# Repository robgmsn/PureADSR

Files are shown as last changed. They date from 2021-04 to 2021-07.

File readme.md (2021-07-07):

DESIGN STATUS: Production

ADSR Updated to V2.21 5/5/21

Library updated to include 3D models.
Traces rerouted.
DAC output filter remodelled.
Power replaced so 5V comes from power supply rather than 12V, in line with low noise techniques.
Code rewritten to be linear, as required by all other GMSN! modules.

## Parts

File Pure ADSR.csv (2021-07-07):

Library | Qty | Parts | Description | Value | Package | SORT
GMSN | 3 | R6, R11, R12 | Resistor | 100k | R0805 | 2
GMSN | 2 | R5, R9 | Resistor | 10k | R0805 | 2
GMSN | 1 | R7 | Resistor | 1M | R0805 | 2
GMSN | 2 | R8, R10 | Resistor | 1k | R0805 | 2
GMSN | 1 | R1 | Resistor | 1k6 | R0805 | 2
GMSN | 1 | R4 | Resistor | 330R | R0805 | 2
GMSN | 6 | C3, C8, C9, C10, C11, C12 | Capacitor | 100nF | C0805 | 3
GMSN | 2 | C1, C2 | Capacitor | 22p | C0805 | 3
GMSN | 3 | C4, C5, C7 | Electro Capacitor | 10u | 153CLV-0505 | 3
GMSN | 2 | D1, D2 | Diode | STTH102A | SMADIODE | 3.9
GMSN | 1 | IC3 | 12bit DAC | MCP4921 | SOIC8 | 4
GMSN | 1 | IC4 | 32-Pin ATMEGA328 | ATMEGA328P | TQFP32-08 | 4
GMSN | 1 | T1 | Generic NPN BJT | MMBT2222A | SOT23 | 4
GMSN | 1 | IC2 | Dual Op Amp | OPAMP_DUALD | SO08 | 4.5
GMSN | 1 | Q1 | Crystal | 20MHz | HC49UP | 5
GMSN | 1 | JP1 | 16 Pin Header 2x8 | HEADER2X8 | POWER_SHROUDED | 7
GMSN | 1 | ISP1 | AVR ISP Header | HEADER2X3-6 | AVRISP | 7
GMSN | 2 | OUTPUT, TRIGATEIN | 3.5 mm Jack Socket | SOCKET_MONO_3.5MMPJ301M-12 | PJ301M-12 | 8
GMSN | 4 | ATTACK, DECAY, RELEASE, SUSTAIN | Pot | 100k | POTENTIOMETER_9MM | 8
GMSN | 1 | MODESW | On-Off-On Switch | ON_OFF_ON | TOGGLE_SW | 9
GMSN | 1 | TRIGGER | Pushbutton LED | PB6149L-5 | PB6149L | 9

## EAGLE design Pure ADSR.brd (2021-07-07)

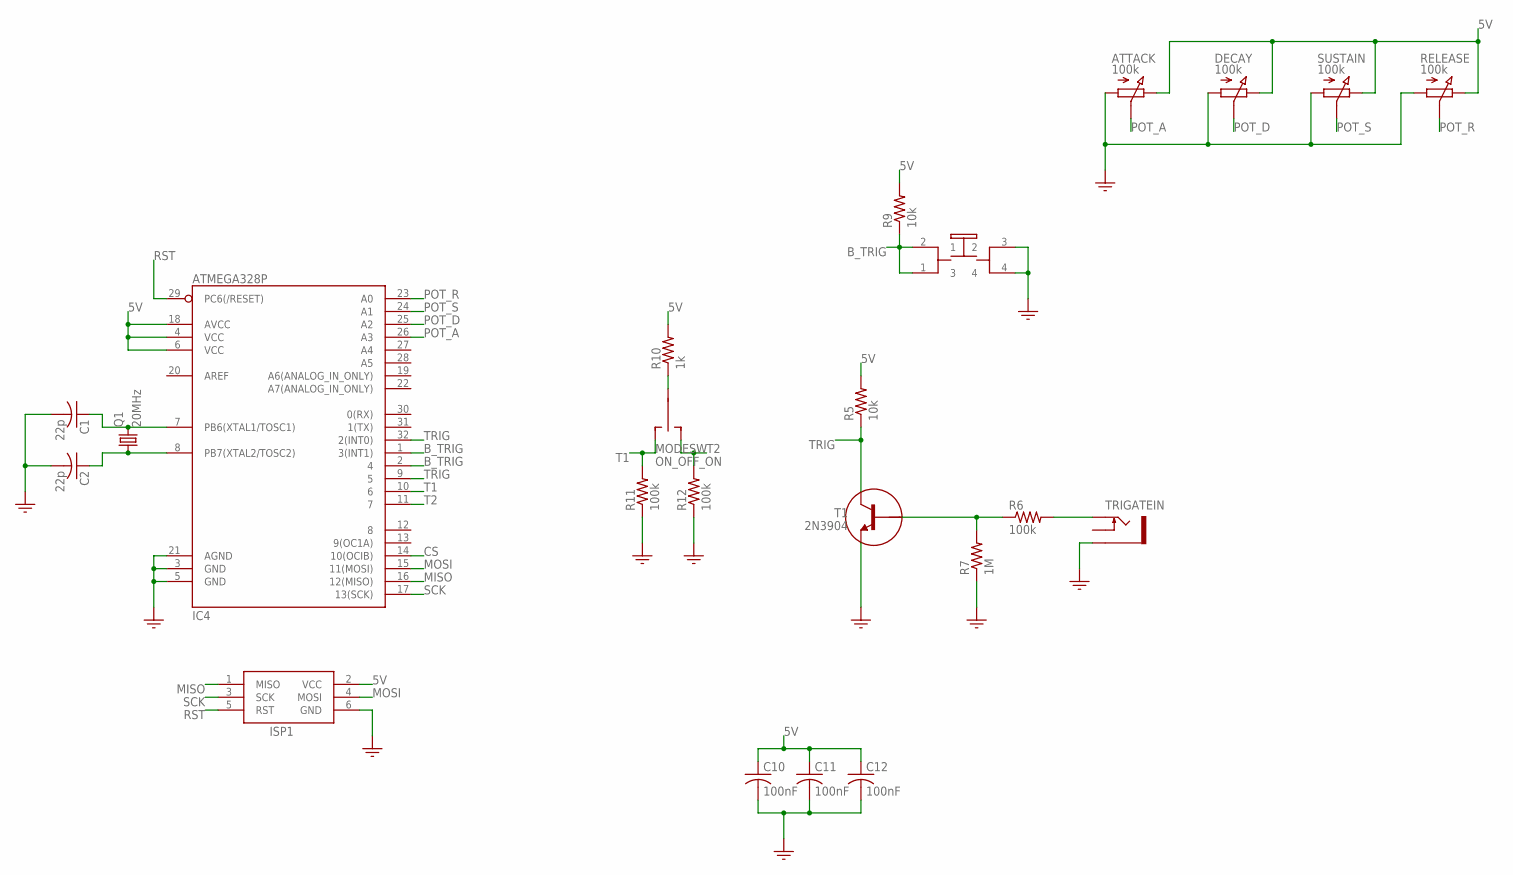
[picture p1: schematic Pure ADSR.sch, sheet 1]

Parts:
ATTACK: 100k; POTENTIOMETER_9MM
C1, C2: 22p; C0805
C10, C11, C12: 100nF; C0805
DECAY: 100k; POTENTIOMETER_9MM
IC4: ATMEGA328P; TQFP32-08
ISP1: HEADER2X3-6; AVRISP
MODESW: ON_OFF_ON; TOGGLE_SW
Q1: 20MHz; HC49UP
R5, R9: 10k; R0805
R6, R11, R12: 100k; R0805
R7: 1M; R0805
R10: 1k; R0805
RELEASE: 100k; POTENTIOMETER_9MM
SUSTAIN: 100k; POTENTIOMETER_9MM
T1: 2N3904; SOT23
TRIGATEIN: SOCKET_MONO_3.5MMPJ301M-12; PJ301M-12
TRIGGER: PB6149L-5; PB6149L

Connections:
5V: ATTACK.P$3 (3), C10.1, C11.1, C12.1, DECAY.P$3 (3), IC4.4 (VCC), IC4.6 (VCC), IC4.18 (AVCC), ISP1.2 (VCC), R5.2, R9.2, R10.2, RELEASE.P$3 (3), SUSTAIN.P$3 (3); also elsewhere on the board
B_TRIG: IC4.1 (3(INT1)), IC4.2 (4), R9.1, TRIGGER.1 (3), TRIGGER.2 (1)
CS: IC4.14 (10(OCIB)); also elsewhere on the board
GND: ATTACK.P$1 (1), C1.2, C2.2, C10.2, C11.2, C12.2, DECAY.P$1 (1), IC4.3 (GND), IC4.5 (GND), IC4.21 (AGND), ISP1.6 (GND), R7.1, R11.1, R12.1, RELEASE.P$1 (1), SUSTAIN.P$1 (1), T1.2 (E), TRIGATEIN.GND (SLEEVE), TRIGGER.3 (2), TRIGGER.4; also elsewhere on the board
MISO: IC4.16 (12(MISO)), ISP1.1 (MISO)
MOSI: IC4.15 (11(MOSI)), ISP1.4 (MOSI); also elsewhere on the board
unnamed: C1.1, IC4.7 (PB6(XTAL1/TOSC1)), Q1.2
unnamed: C2.1, IC4.8 (PB7(XTAL2/TOSC2)), Q1.1
unnamed: MODESW.2, R10.1
unnamed: R6.1, R7.2, T1.1 (B)
unnamed: R6.2, TRIGATEIN.TIP
POT_A: ATTACK.P$2 (2), IC4.26 (A3)
POT_D: DECAY.P$2 (2), IC4.25 (A2)
POT_R: IC4.23 (A0), RELEASE.P$2 (2)
POT_S: IC4.24 (A1), SUSTAIN.P$2 (2)
RST: IC4.29 (PC6(/RESET)), ISP1.5 (RST)
SCK: IC4.17 (13(SCK)), ISP1.3 (SCK); also elsewhere on the board
T1: IC4.10 (6), MODESW.3 (S), R11.2
T2: IC4.11 (7), MODESW.1 (O), R12.2
TRIG: IC4.9 (5), IC4.32 (2(INT0)), R5.1, T1.3 (C)

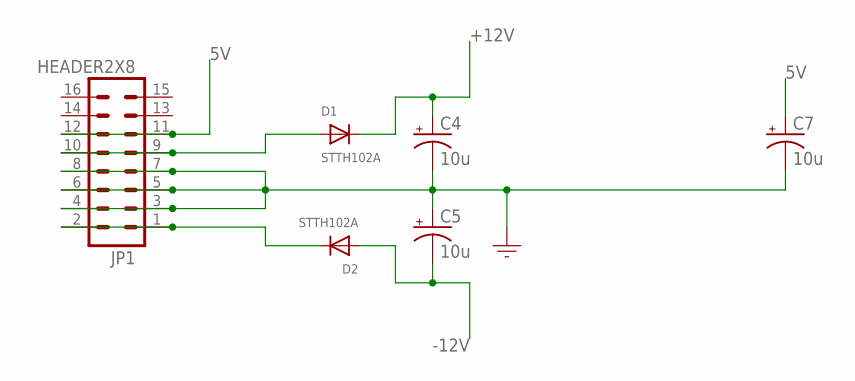
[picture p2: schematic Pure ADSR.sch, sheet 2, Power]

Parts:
C4, C5, C7: 10u; 153CLV-0505
D1, D2: STTH102A; SMADIODE
JP1: HEADER2X8; POWER_SHROUDED

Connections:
5V: C7.+, JP1.11, JP1.12; also elsewhere on the board
+12V: C4.+, D1.C; also elsewhere on the board
-12V: C5.-, D2.A; also elsewhere on the board
GND: C4.-, C5.+, C7.-, JP1.3, JP1.4, JP1.5, JP1.6, JP1.7, JP1.8; also elsewhere on the board
unnamed: D2.C, JP1.1, JP1.2
unnamed: D1.A, JP1.9, JP1.10

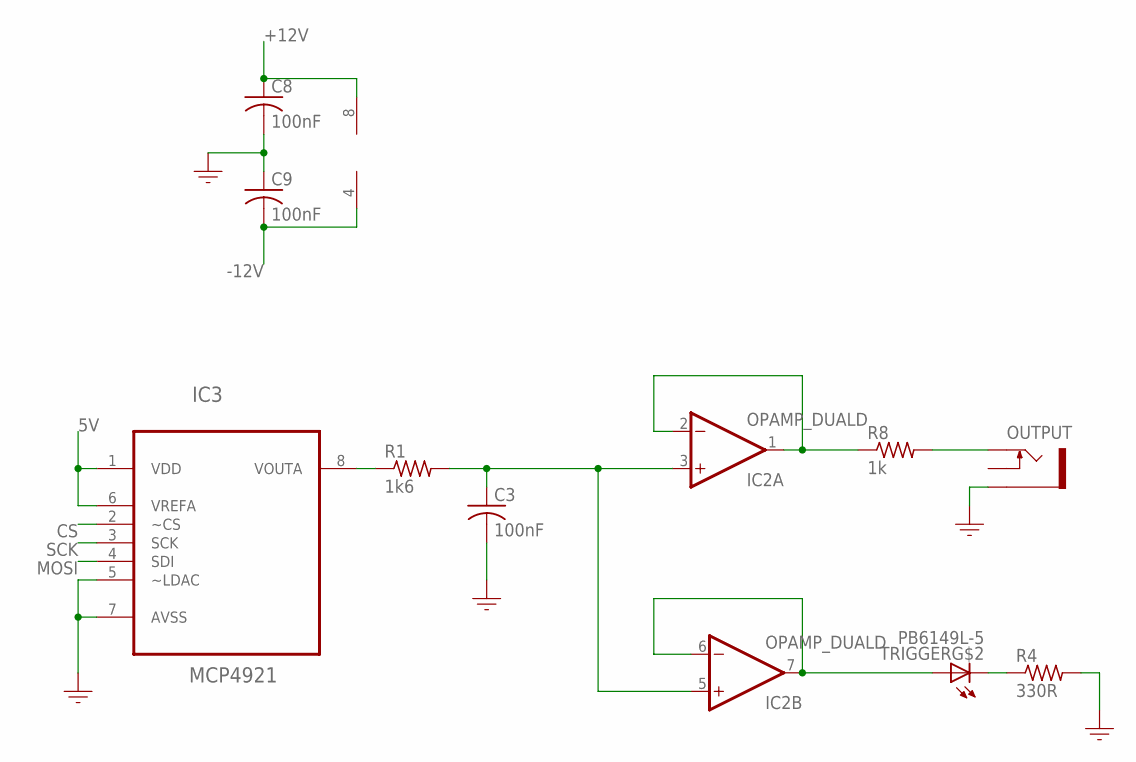
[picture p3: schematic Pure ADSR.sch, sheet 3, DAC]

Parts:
C3, C8, C9: 100nF; C0805
IC2: OPAMP_DUALD; SO08
IC3: MCP4921; SOIC8
OUTPUT: SOCKET_MONO_3.5MMPJ301M-12; PJ301M-12
R1: 1k6; R0805
R4: 330R; R0805
R8: 1k; R0805
TRIGGER: PB6149L-5; PB6149L

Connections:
5V: IC3.1 (VDD), IC3.6 (VREFA); also elsewhere on the board
+12V: C8.1, IC2.8 (V+); also elsewhere on the board
-12V: C9.2, IC2.4 (V-); also elsewhere on the board
CS: IC3.2 (~CS); also elsewhere on the board
GND: C3.2, C8.2, C9.1, IC3.5 (~LDAC), IC3.7 (AVSS), OUTPUT.GND (SLEEVE), R4.2; also elsewhere on the board
MOSI: IC3.4 (SDI); also elsewhere on the board
unnamed: IC3.8 (VOUTA), R1.1
unnamed: C3.1, IC2.3 (+IN), IC2.5 (+IN), R1.2
unnamed: IC2.1 (OUT), IC2.2 (-IN), R8.1
unnamed: IC2.6 (-IN), IC2.7 (OUT), TRIGGER.A
unnamed: R4.1, TRIGGER.K (C)
unnamed: OUTPUT.TIP, R8.2
SCK: IC3.3 (SCK); also elsewhere on the board

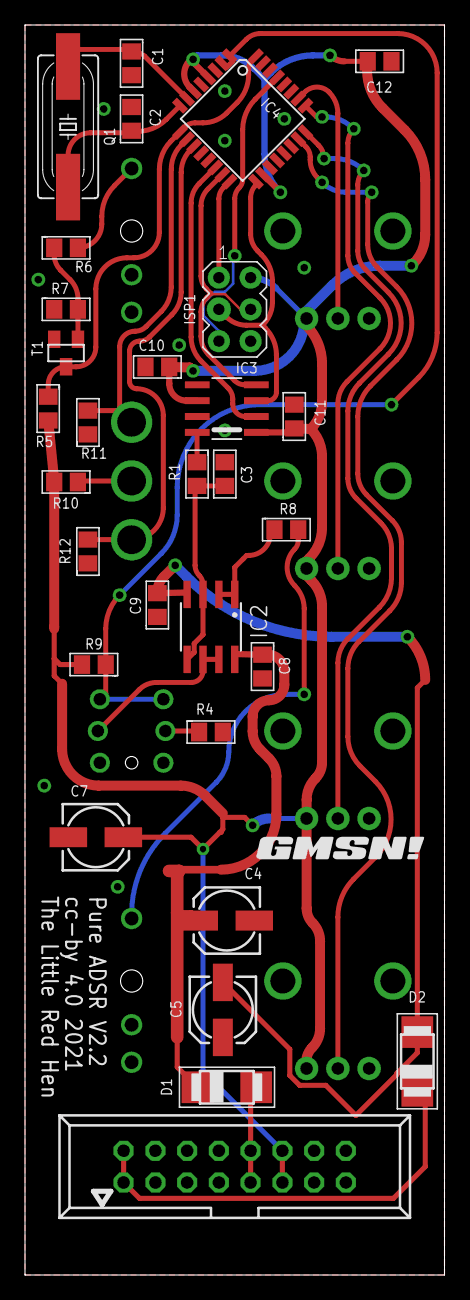
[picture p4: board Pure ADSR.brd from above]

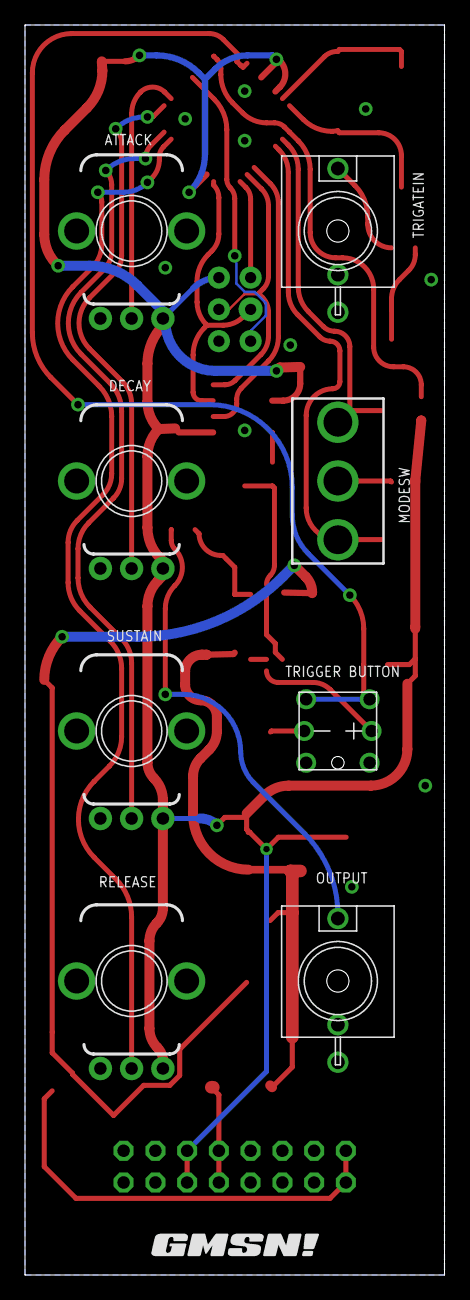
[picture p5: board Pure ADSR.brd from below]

Board: 2 copper layers, 33.6 x 100.0 mm, 40 parts (9 on the bottom side), 30 nets.

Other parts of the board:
U$1, U$2: GMSN!_LOGO

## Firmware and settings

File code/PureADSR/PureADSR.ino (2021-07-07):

/*

  GMSN Pure ADSR v20170915
  Rob Spencer 2017
  cc-by 4.0

  Full Open Source Documentation at https://gmsn.co.uk/pure-adsr including hardware files, Bill of Materials, Mouser Cart and Help Videos

  For more indepth build and general support chat, join us at the GMSN! Synth Design Slack: https://join.slack.com/t/gmsnsynthdesign/shared_invite/MjE0NzM1ODc3NDkyLTE1MDA0NTI1MTItODQ3MDM4OTdlYw

*/

#include "SPI.h"

//Setup pin variables
const byte dacCS = 10; //14
const byte trigIn = 2; //32
const byte trigBut = 4; //2
const byte modeSw1 = 6; //10
const byte modeSw2 = 7; //11

const byte knob1 = A3; //26
const byte knob2 = A2; //25
const byte knob3 = A1; //24
const byte knob4 = A0; //23

//Setup envelope variable
int aPot, enVal = 0, dPot, sPot, sVal, rPot, onPot, offPot;

//Setup state variables
boolean gate = 0, rising = 0;
byte mode, phase = 0;
int trapOnCount = 0, trapOffCount = 0;

//Setup switch debounce variables
int buttonState, lastButtonState = HIGH;
unsigned long lastDebounceTime = 0, debounceDelay = 50;


void setup() {

  //Start DAC Comms
  SPI.begin();
  SPI.setBitOrder(MSBFIRST);

  //Configure Pins
  pinMode(dacCS, OUTPUT); //DAC CS
  pinMode(trigIn, INPUT); //TRIGGER IN
  pinMode(trigBut, INPUT); //Button
  pinMode(modeSw1, INPUT); //MODE SW1
  pinMode(modeSw2, INPUT); //MODE SW2
  digitalWrite(dacCS, HIGH);

  attachInterrupt(digitalPinToInterrupt(trigIn), gateOn, FALLING);



}

void loop() {

  //Poll the Mode switch to set the mode
  if (digitalRead(modeSw2) == HIGH) {
    mode = 1;
  } else if (digitalRead(modeSw1) == LOW && digitalRead(modeSw2) == LOW) {
    mode = 2;
  } else {
    mode = 3;
  }

 

  //Control logic which calls the functions
  switch (phase) {

    //Phase 0 is idle, but if it's in the Trap mode it kicks it back into the Attack phase.
    case 0:
      if (mode == 3) {
        phase = 1;
      }
      break;

    //Attack Phase with some logic to kick it into the correct next phase depending on the Mode.
    case 1:
      attack();

      if (enVal >= 4095) {
        switch (mode) {
          case 1:
            phase = 2;
            break;

          case 2:
            phase = 3;
            break;

          case 3:
            phase = 4;
            break;
        }
      }

      if (mode == 1 && digitalRead(trigBut) == HIGH && digitalRead(trigIn) == HIGH) {
        phase = 3;
      }
      break;

    //Decay to Sustain Phase.
    case 2:
      decaySustain();
      if (mode == 1 && digitalRead(trigBut) == HIGH && digitalRead(trigIn) == HIGH) {
        phase = 3;
      }
      break;

    //Release Phase. If it's in ADSR or AR mode, then knob 4 is the Release. If it's in Trap mode, then it's knob 3.
    case 3:
      if (mode == 3) {
        releasePhase(knob3);
      } else {
        releasePhase(knob4);
      }
      if (enVal < 100) {
        enVal = 0;
        if (mode == 3) {
          phase = 5;
        } else {
          phase = 0;
        }
      }
      break;

    //Phase 4, Trap On
    case 4:
      trapOn();
      break;

    //Phase 5, Trap Off
    case 5:
      trapOff();
      break;
  }


  //Poll Trigger Button, debounce, initialise Up phase
  trigButton();
}

void attack() {
  aPot = fscale(0, 1024, 100, 1, analogRead(knob1), 10);
  if (aPot > 2999) {
    enVal = 4095;
  } else {
    enVal = enVal + aPot;
    if (enVal > 4090) {
      enVal = 4095;
    }
  }
  mcpWrite((int)enVal);
}

void decaySustain() {
  dPot = fscale(0, 1024, 100, 1, analogRead(knob2), 10);
  sPot = map(analogRead(knob3), 0, 1024, 0, 4096);
  if (enVal <= sPot) {
    enVal = sPot;
  } else {
    enVal = enVal - dPot;
  }
  mcpWrite((int)enVal);
}

void releasePhase(byte knob) {
  rPot = fscale(0, 1024, 100, 0, analogRead(knob), 10);
  enVal = enVal - rPot;
  mcpWrite((int)enVal);
}

void trapOn() {
  mcpWrite((int)enVal);
  onPot = fscale(0, 1024, 0, 30000, analogRead(knob2), -7);
  if (trapOnCount >= onPot) {
    trapOnCount = 0;
    phase = 3;
  } else {
    trapOnCount++;
  }
}

void trapOff() {
  mcpWrite((int)enVal);
  offPot = fscale(0, 1024, 0, 30000, analogRead(knob4), -7);
  if (trapOffCount >= offPot) {
    trapOffCount = 0;
    phase = 1;
  } else {
    trapOffCount++;
  }
}


/*Debounce routine for the switch. Switches are very noises when they are switching.
  When you press a switch, the mechanism can "bounce" on, off, on, off, on, etc, in the space of a few milliseconds.
  This debounce function removes the noise.*/
void trigButton() {
  int reading = digitalRead(trigBut);

  if ((millis() - lastDebounceTime) > debounceDelay) {

    if (reading != buttonState) {
      buttonState = reading;
      if (buttonState == LOW) {
        gateOn();
        lastDebounceTime = millis();
      }
    }
  }
  lastButtonState = reading;
}

//Interrupt routine for rising edge of Gate
void gateOn() {
  if (phase == 1) {
    enVal = 1;
  } else {
    phase = 1;
  }
  trapOffCount = 0;
  trapOnCount = 0;
}

/*Writing to the DAC.
  The whole purpose of the module is to output a voltage envelope. That voltage then controls another module, such as a VCA or a filter.
  In order to get that voltage out, we need to convert the value of the "envValue" variable into a voltage, which is done by a Digital to Analogue Converter, or DAC for short.
  The function below send envValue to the DAC for conversion to the analogue voltage.
  0 = Off 4095 = Full on.*/
void mcpWrite(int value) {
  value = value + 28672;
  digitalWrite(dacCS, LOW);
  SPI.transfer16(value);
  digitalWrite(dacCS, HIGH);
}

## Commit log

2021-04-16 ADSR 2.0
    [Pure ADSR.brd, Pure ADSR.sch]
2021-04-16 ADSR 2.1
    [Pure ADSR.brd, Pure ADSR.sch]
2021-04-16 ADSR 2.2
    ADSR Updated to V2.2 14/4/21
    Library updated to include 3D models.
    Traces rerouted.
    DAC output filter remodelled.
    Power replaced so 5V comes from power supply rather than 12V, in line with low noise techniques.
    [Pure ADSR PCB Panel.brd, Pure ADSR.brd, Pure ADSR.csv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]

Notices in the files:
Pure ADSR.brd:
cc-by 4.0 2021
